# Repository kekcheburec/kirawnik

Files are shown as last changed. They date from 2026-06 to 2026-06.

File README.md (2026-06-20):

# kirawnik

> From Belarusian: head, manager

Compact ESP32-C6 board for powering on or rebooting a Framework Desktop over Zigbee or Wi-Fi.

kirawnik 3d view

## Overview

kirawnik sits between the motherboard and the case power button cable. It uses the 5V SB pin exposed on the Framework Desktop front panel connector, keeping the ESP32-C6 powered even while the system is shut down or asleep.

For easier installation, the board has silkscreen markings for the cable connections. The external antenna should be connected to the uFL (a.k.a u.FL / IPX / IPEX) connector and mounted on non-metal parts.

Firmware can be built manually or with ESPHome. With ESP32-C6 Zigbee support, the board can connect to many smart home systems and work offline.

## References

- [Front panel connector location and pinout](https://knowledgebase.frame.work/front-panel-io-connectors-amd-ryzen-ai-max-300-series-Hk3SXolHxg)
- [Framework Desktop motherboard connector schematic](https://github.com/FrameworkComputer/Framework-Desktop/blob/main/Mainboard/Mainboard_Interfaces_Schematic_Framework_Desktop_Ryzen_AI_Max.pdf)

## Disclaimer

No warranties of any kind

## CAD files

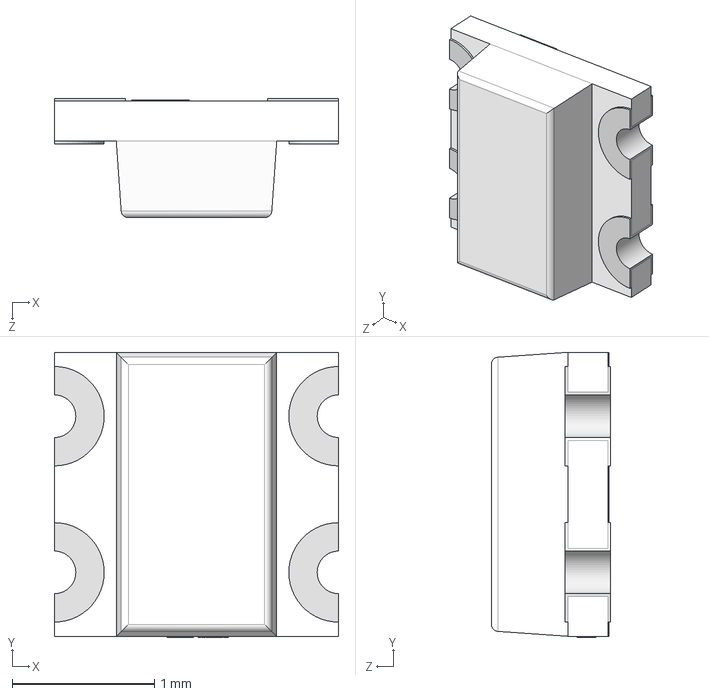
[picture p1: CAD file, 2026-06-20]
3d/LED-SMD_4P-L2.0-W2.0-TL_WS2812B-2020.step
2.00 x 2.01 x 0.84 mm

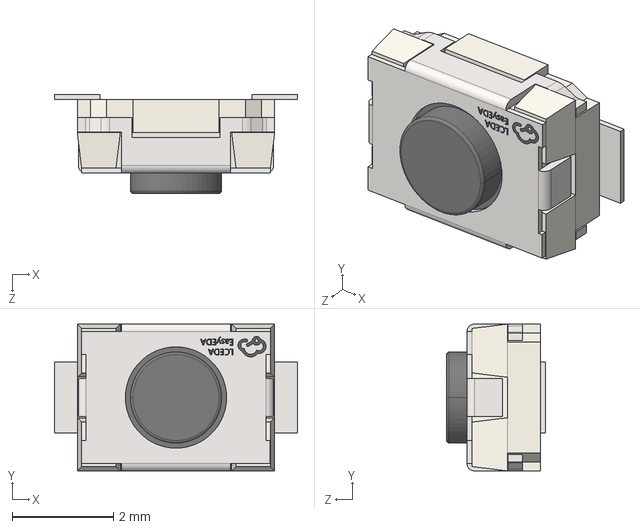
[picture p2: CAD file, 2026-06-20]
3d/SW-SMD_L3.9-W3.0-P4.45.step
4.80 x 2.90 x 1.95 mm

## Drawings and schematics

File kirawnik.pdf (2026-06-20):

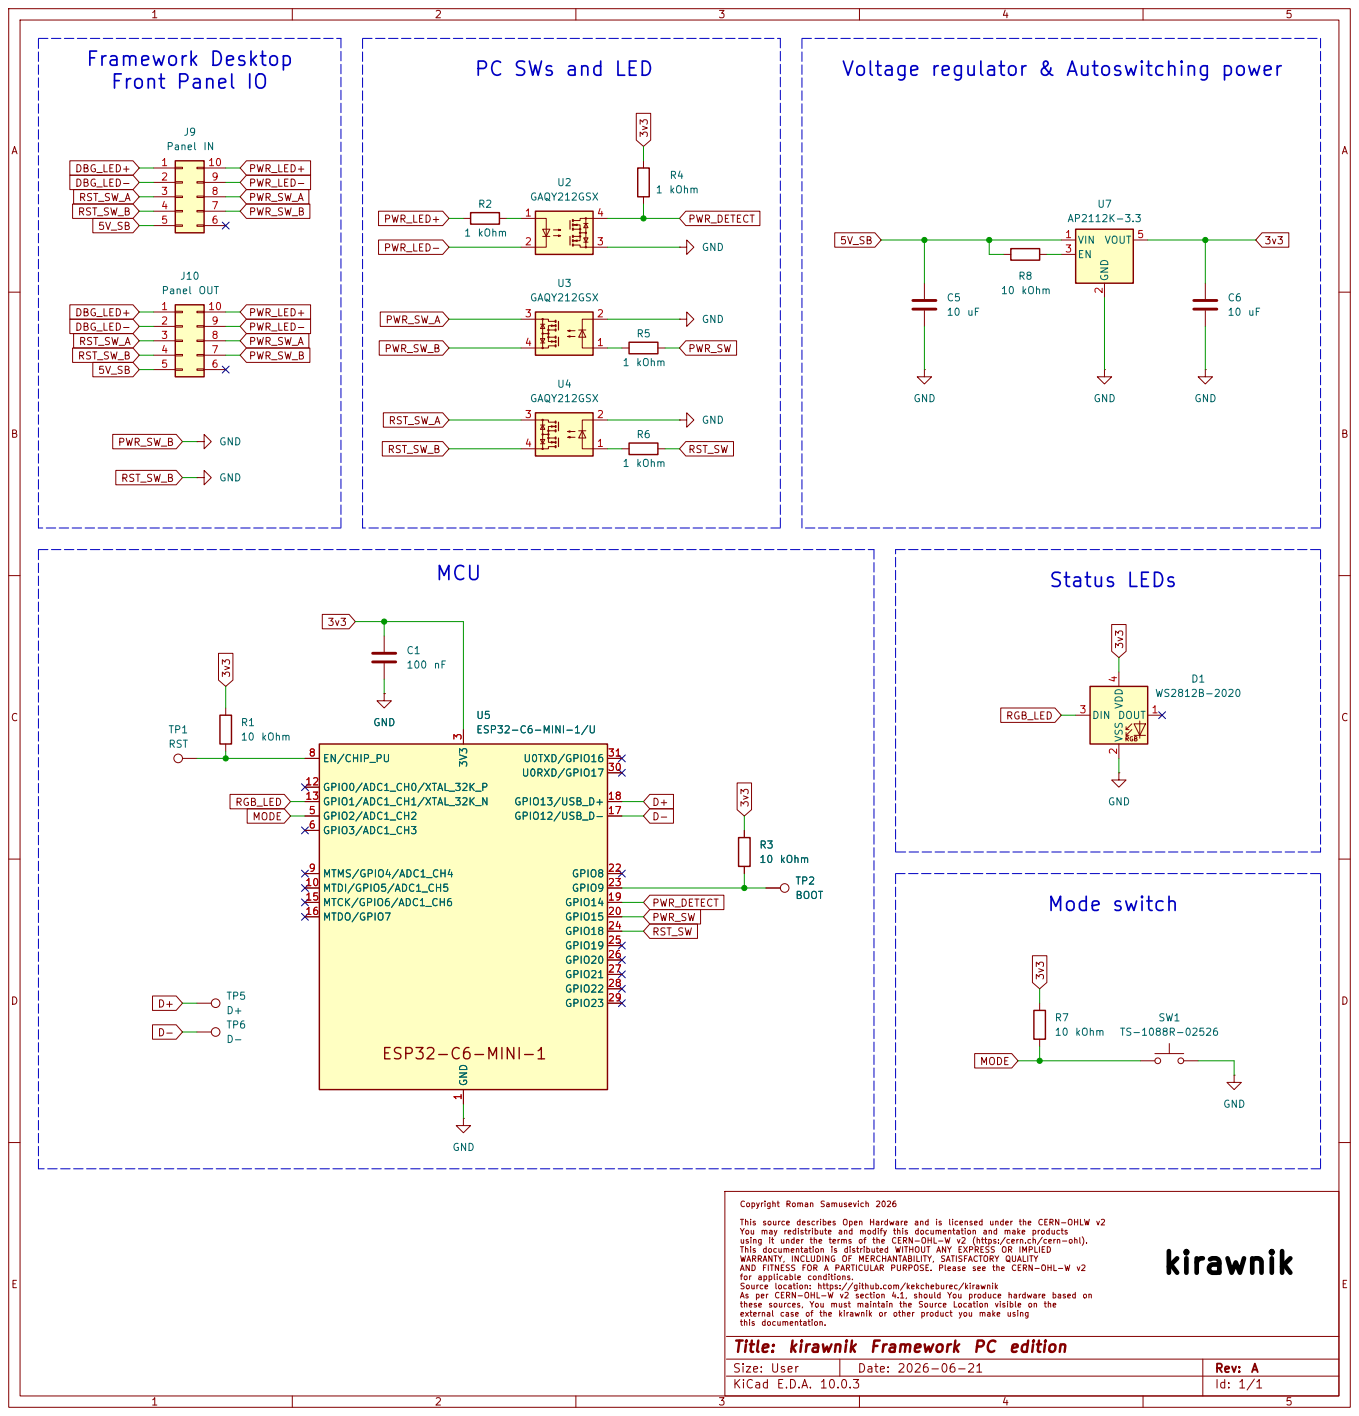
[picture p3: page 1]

PC SWs and LED

This source describes Open Hardware and is licensed under the CERN-OHLW v2
You may redistribute and modify this documentation and make products using it under the terms of the CERN-OHL-W v2 (https:/cern.ch/cern-ohl). This documentation is distributed WITHOUT ANY EXPRESS OR IMPLIED WARRANTY, INCLUDING OF MERCHANTABILITY, SATISFACTORY QUALITY

AND FITNESS FOR A PARTICULAR PURPOSE. Please see the CERN-OHL-W v2
for applicable conditions. Source location: https://github.com/kekcheburec/kirawnik As per CERN-OHL-W v2 section 4.1, should You produce hardware based on

these sources, You must maintain the Source Location visible on the
external case of the kirawnik or other product you make using
Title: kirawnik Framework PC edition

Size: User | Rev: A
KiCad E.D.A. 10.0.3 | Id: 1/1

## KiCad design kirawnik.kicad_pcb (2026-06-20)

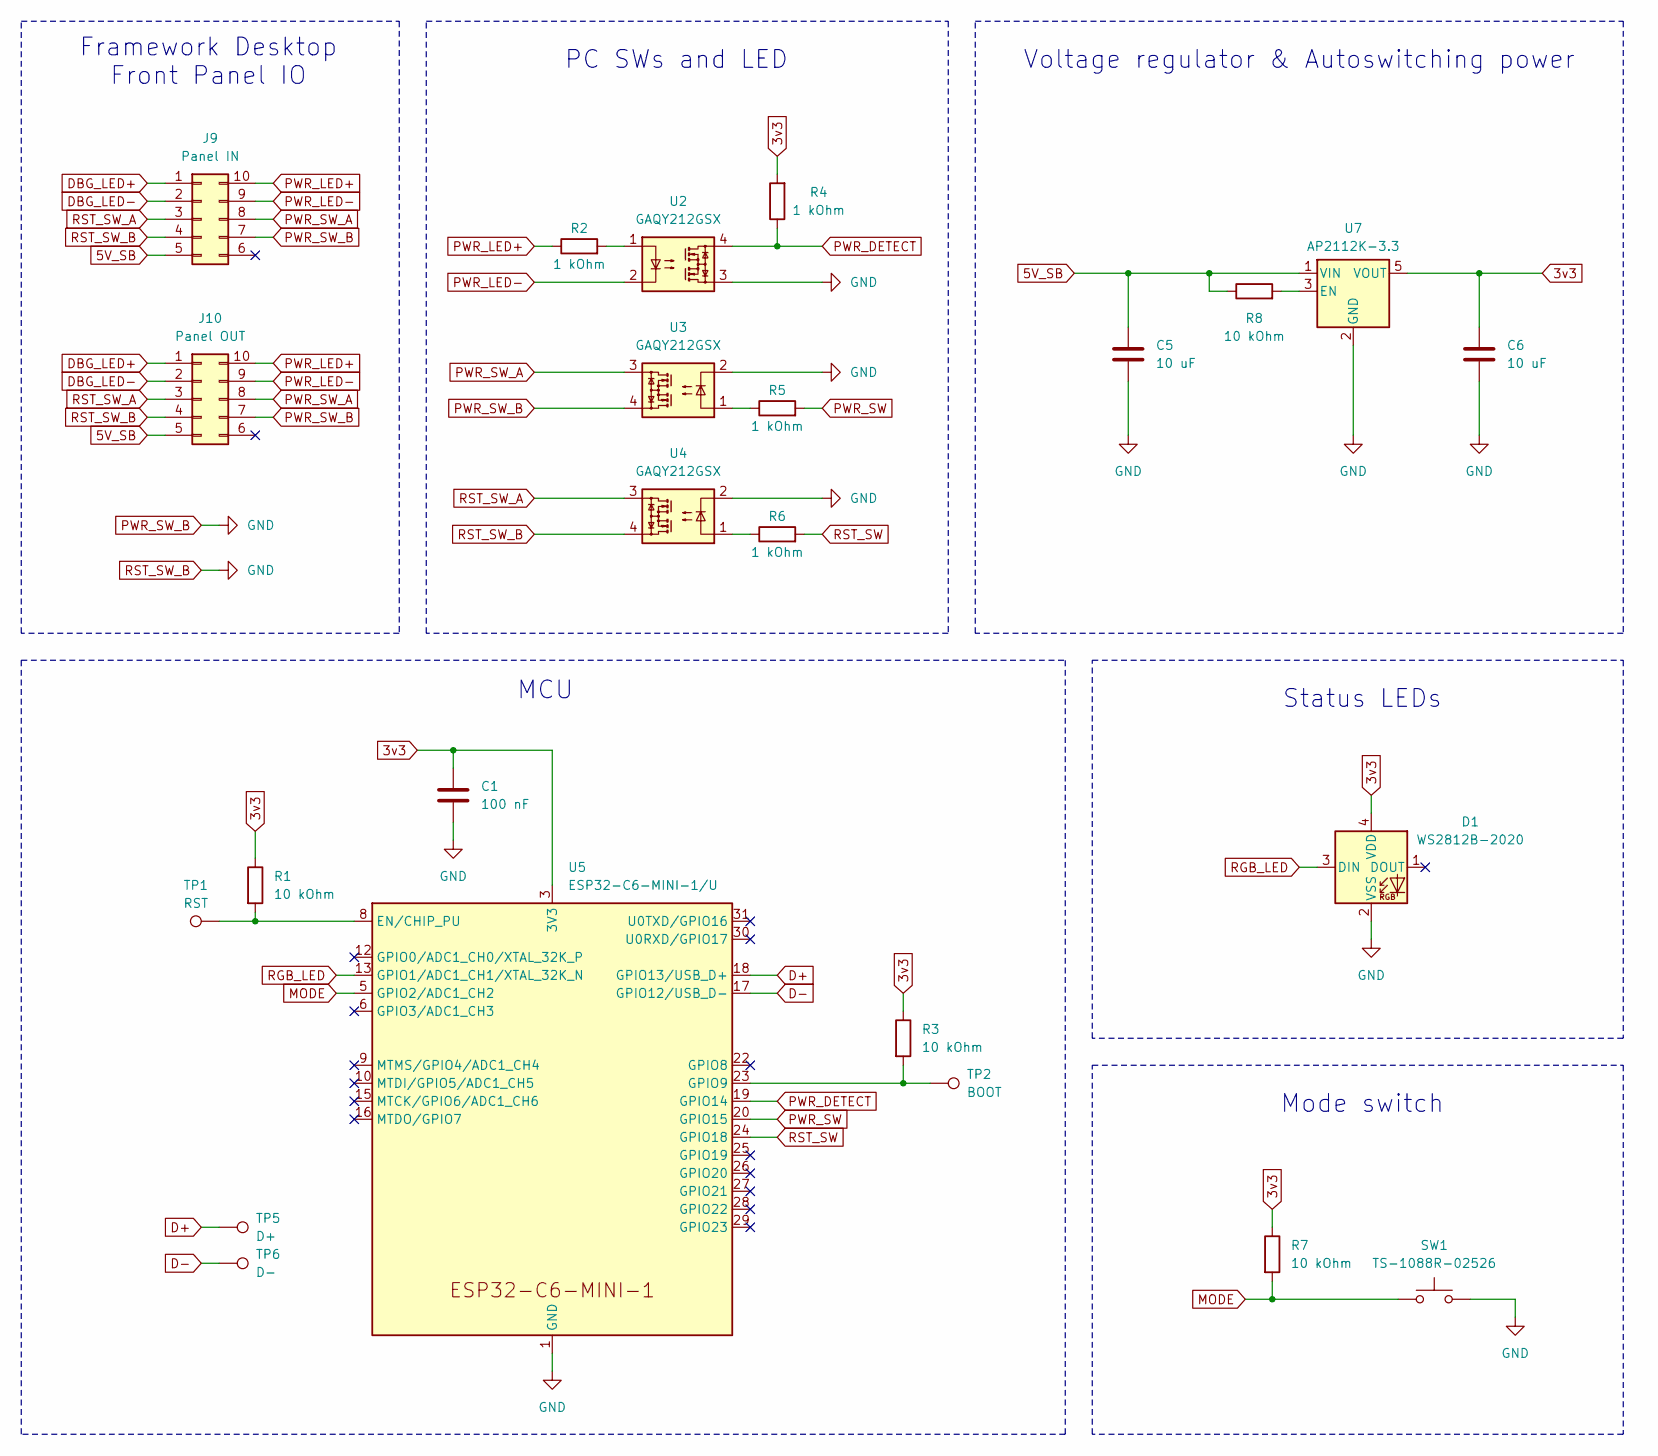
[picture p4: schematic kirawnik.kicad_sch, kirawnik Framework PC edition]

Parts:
C1: 100 nF; C_0402_1005Metric; LCSC Part # C1525
C5, C6: 10 uF; C_0402_1005Metric; LCSC Part # C15525
D1: WS2812B-2020; LED_WS2812B-2020_PLCC4_2.0x2.0mm; LCSC Part # C965555
J9: Panel IN; FrontIOPinSocket_2x05_P2.54mm_Horizontal
J10: Panel OUT; FrontIOPinHeader_2x05_P2.54mm_Horizontal
R1, R3, R7, R8: 10 kOhm; R_0402_1005Metric; LCSC Part # C25744
R2, R4, R5, R6: 1 kOhm; R_0402_1005Metric; LCSC Part # C11702
SW1: TS-1088R-02526; LCSC Part # C455281
TP1: RST; TestPoint_Pad_D1.0mm
TP2: BOOT; TestPoint_Pad_D1.0mm
TP5: D+; TestPoint_Pad_D1.0mm
TP6: D-; TestPoint_Pad_D1.0mm
U2, U3, U4: GAQY212GSX; SOP-4_3.8x4.1mm_P2.54mm; LCSC Part # C19271988
U5: ESP32-C6-MINI-1/U; ESP32-C6-MINI-1U; LCSC Part # C20627095
U7: AP2112K-3.3; SOT-23-5; LCSC Part # C51118

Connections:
3v3: C1.1, C6.1, D1.4 (VDD), R1.1, R3.1, R4.2, R7.1, U5.3 (3V3), U7.5 (VOUT)
5V_SB: C5.1, J9.5, J10.5, R8.1, U7.1 (VIN)
D+: TP5.1, U5.18 (GPIO13/USB_D+)
D-: TP6.1, U5.17 (GPIO12/USB_D-)
DBG_LED+: J9.1, J10.1
DBG_LED-: J9.2, J10.2
MODE: R7.2, SW1.1, U5.5 (GPIO2/ADC1_CH2)
unnamed: R2.2, U2.1
unnamed: R5.1, U3.1
unnamed: R6.1, U4.1
unnamed: R1.2, TP1.1, U5.8 (EN/CHIP_PU)
unnamed: R3.2, TP2.1, U5.23 (GPIO9)
unnamed: R8.2, U7.3 (EN)
PWR_DETECT: R4.1, U2.4, U5.19 (GPIO14)
PWR_LED+: J9.10, J10.10, R2.1
PWR_LED-: J9.9, J10.9, U2.2
PWR_SW: R5.2, U5.20 (GPIO15)
PWR_SW_A: J9.8, J10.8, U3.3
PWR_SW_B: C1.2, C5.2, C6.2, D1.2 (VSS), J9.4, J9.7, J10.4, J10.7, SW1.2, U2.3, U3.2, U3.4, U4.2, U4.4, U5.1 (GND), U5.2 (GND), U5.11 (GND), U5.14 (GND), U5.36 (GND), U5.37 (GND), U5.38 (GND), U5.39 (GND), U5.40 (GND), U5.41 (GND), U5.42 (GND), U5.43 (GND), U5.44 (GND), U5.45 (GND), U5.46 (GND), U5.47 (GND), U5.48 (GND), U5.49 (GND), U5.50 (GND), U5.51 (GND), U5.52 (GND), U5.53 (GND), U7.2 (GND)
RGB_LED: D1.3 (DIN), U5.13 (GPIO1/ADC1_CH1/XTAL_32K_N)
RST_SW: R6.2, U5.24 (GPIO18)
RST_SW_A: J9.3, J10.3, U4.3

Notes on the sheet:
MCU
Mode switch
Status LEDs
Framework Desktop Front Panel IO
Voltage regulator & Autoswitching power
PC SWs and LED

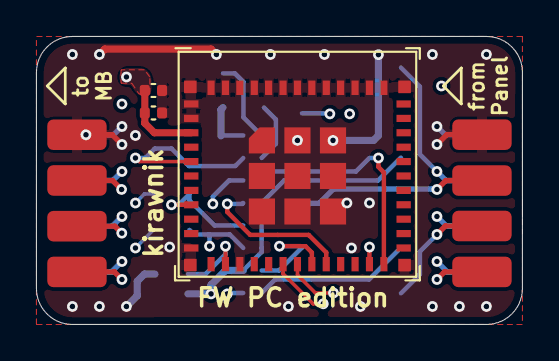
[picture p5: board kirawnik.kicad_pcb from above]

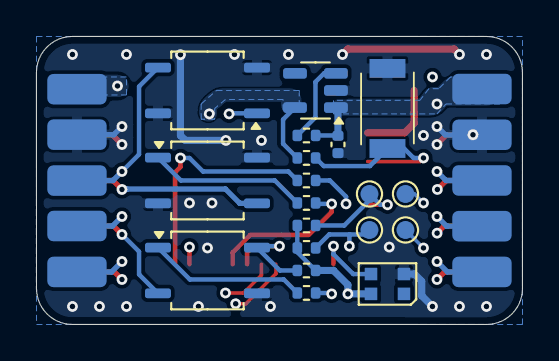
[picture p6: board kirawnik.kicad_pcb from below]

Board: 4 copper layers, 27.0 x 16.0 mm, 24 parts (21 on the bottom side), 22 nets.

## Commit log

2026-06-20 Add kirawnik files and other changes
    [LED-SMD_4P-L2.0-W2.0-TL_WS2812B-2020.step, SW-SMD_L3.9-W3.0-P4.45.step, kirawnik.kicad_pcb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]
2026-06-20 Update 3d model and render settings
    [kirawnik.kicad_pcb]
